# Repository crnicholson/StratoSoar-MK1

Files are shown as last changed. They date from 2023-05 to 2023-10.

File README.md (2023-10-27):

<picture>
 <source media="(prefers-color-scheme: dark)" srcset="https://github.com/charlienicholson3/StratoSoar/blob/main/schematic.png?raw=true">
 <source media="(prefers-color-scheme: light)" srcset="https://github.com/charlienicholson3/StratoSoar/blob/main/schematic.png?raw=true">
 YOUR-ALT-TEXT
</picture>

# UPDATE: This project is on its second year in a different repo as StratoSoar MK2. Link here: https://github.com/charlienicholsonr/StratoSoar-MK2.

### NOTE: This PCB is wrong. We had to add a wire to the board. I suggest designing your own PCB.

# StratoSoar MK1
My repo for the StratoSoar project. The LightAPRS code is just a variation of the original code. This system is made to recover unmanned high-altitude gliders, launched from weather balloons. It also has sensors that write to EEPROM, and the power for that system is controlled by the main MCU, which is the LightAPRS. For those who do not know, APRS is a form of HAM radio. You need to be a HAM radio operator to do it. For those who do not know, LightAPRS W-2 is a lightweight APRS transmitter: github.com/lightaprs/LightAPRS-W-2.0. The PCB takes anything from 20 to 6 volts as input and turns off the sensor and the camera after a certain altitude. It can also control the recording of the video. The schematic shows everything. The PCB breaks into three parts: top, middle, and bottom layers that connect through header pins.

# Acknowledgements
Thanks to Harish KC1SIO for the idea and initial work. Thanks to the NEWBS team for fostering the idea and having the high altitude project. Special thanks to Max W0MXX and Seth KC1PZY for funding and help during this project. Thanks to Bob K5TEC at NeSciTech for supplying a workspace and collaboration area. 

# Nerd info
We used a RunCam DVR with a 2N2222 transistor to close the circuit where the button is mounted. This took lots of development and didn't always go right. It highly depends on the voltage of the MCU and the amount of current your MCU can sink into the base pin of the transistor. Because of this, we had to not use the Serial Wombat and to solder a wire onto the LightAPRS. The SerialWombat can still be used to power the MOSFET, though it should be noted that the voltage goes through a series of transistor amplifiers to have enough voltage to turn on the FET. The camera on the DVR was a RunCam Atom.

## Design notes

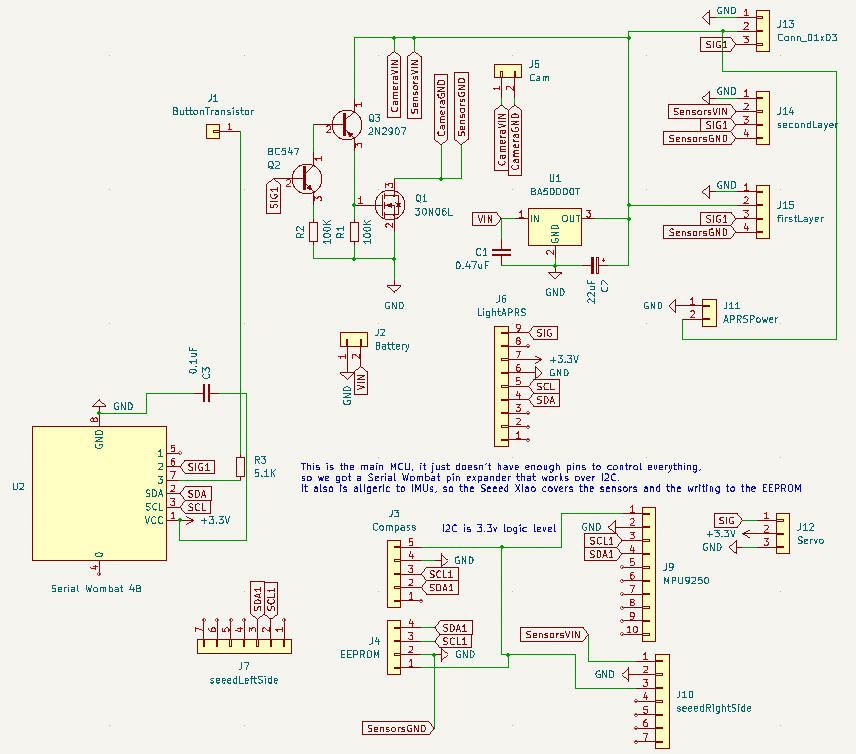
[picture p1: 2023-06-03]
schematic.png

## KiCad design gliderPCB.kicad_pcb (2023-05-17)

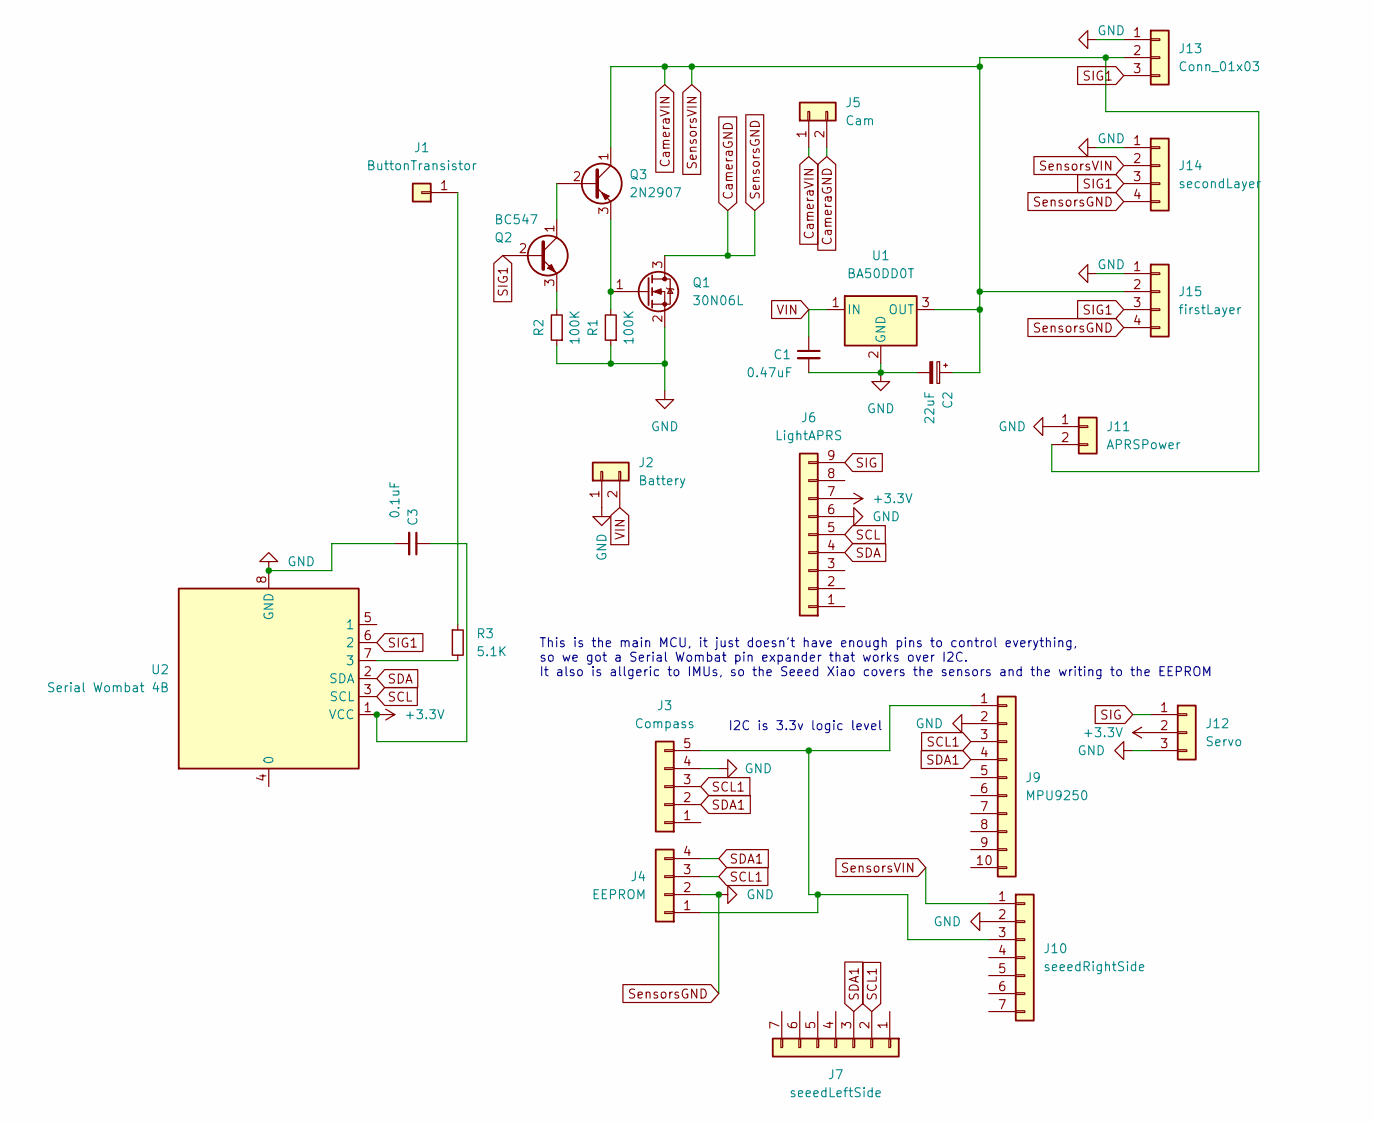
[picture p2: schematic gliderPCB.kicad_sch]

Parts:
C1: 0.47uF; C_Disc_D4.3mm_W1.9mm_P5.00mm
C2: 22uF; CP_Radial_D5.0mm_P2.50mm
C3: 0.1uF; C_Disc_D4.3mm_W1.9mm_P5.00mm
J1: ButtonTransistor; PinHeader_1x01_P2.54mm_Vertical
J2: Battery; PinHeader_1x02_P2.54mm_Vertical
J3: Compass; PinHeader_1x05_P2.54mm_Vertical
J4: EEPROM; PinHeader_1x04_P2.54mm_Vertical
J5: Cam; PinHeader_1x02_P2.54mm_Vertical
J6: LightAPRS; PinHeader_1x09_P2.54mm_Vertical
J7: seeedLeftSide; PinHeader_1x07_P2.54mm_Vertical
J9: MPU9250; PinHeader_1x10_P2.54mm_Vertical
J10: seeedRightSide; PinHeader_1x07_P2.54mm_Vertical
J11: APRSPower; PinHeader_1x02_P2.54mm_Vertical
J12: Servo; PinHeader_1x03_P2.54mm_Vertical
J13: Conn_01x03; PinHeader_1x03_P2.54mm_Vertical
J14: secondLayer; PinHeader_1x04_P2.54mm_Vertical
J15: firstLayer; PinHeader_1x04_P2.54mm_Vertical
Q1: 30N06L; TO-220-3_Vertical
Q2: BC547; TO-92L_Inline
Q3: 2N2907; TO-92L_Inline
R1, R2: 100K; R_Axial_DIN0207_L6.3mm_D2.5mm_P10.16mm_Horizontal
R3: 5.1K; R_Axial_DIN0207_L6.3mm_D2.5mm_P10.16mm_Horizontal
U1: BA50DD0T; TO-220F-3_Vertical
U2: Serial Wombat 4B; DIP-8_W7.62mm

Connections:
+3.3V: C3.1, J6.7, J12.2, U2.1 (VCC)
CameraGND: C1.2, C2.2, C3.2, J2.1, J3.4, J4.2, J5.2, J6.6, J9.2, J10.2, J11.1, J12.3, J13.1, J14.1, J14.4, J15.1, J15.4, Q1.2 (S), Q1.3 (D), R1.1, R2.1, U1.2 (GND), U2.8 (GND)
CameraVIN: C2.1, J5.1, J10.1, J11.2, J13.2, J14.2, J15.2, Q3.1 (C), U1.3 (OUT)
unnamed: J1.1, R3.1
unnamed: J3.5, J4.1, J9.1, J10.3
unnamed: Q1.1 (G), Q3.3 (E), R1.2
unnamed: Q2.1 (C), Q3.2 (B)
unnamed: Q2.3 (E), R2.2
unnamed: R3.2, U2.7 (3)
SCL: J6.5, U2.3 (SCL)
SCL1: J3.3, J4.3, J7.2, J9.3
SDA: J6.4, U2.2 (SDA)
SDA1: J3.2, J4.4, J7.3, J9.4
SIG: J6.9, J12.1
SIG1: J13.3, J14.3, J15.3, Q2.2 (B), U2.6 (2)
VIN: C1.1, J2.2, U1.1 (IN)

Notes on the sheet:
I2C is 3.3v logic level
This is the main MCU, it just doesn't have enough pins to control everything, so we got a Serial Wombat pin expander that works over I2C. It also is allgeric to IMUs, so the Seeed Xiao covers the sensors and the writing to the EEPROM

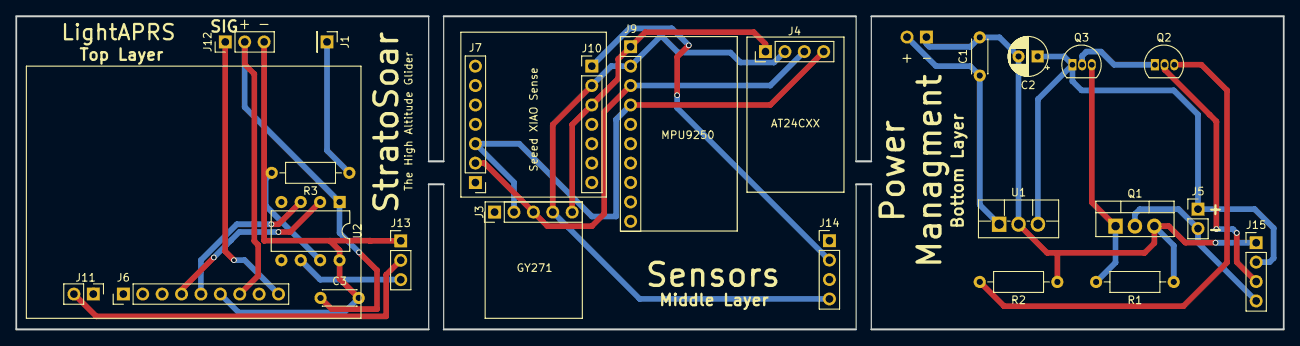
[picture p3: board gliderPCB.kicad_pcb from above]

Board: 2 copper layers, 166.0 x 41.0 mm, 25 parts (1 on the bottom side), 16 nets.

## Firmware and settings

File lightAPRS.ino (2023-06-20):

#include <Arduino.h>
#include <SPI.h>
#include <Wire.h>
#include <math.h>
#include <stdio.h>
#include <avr/dtostrf.h>
#include <ZeroAPRS.h>                       //https://github.com/hakkican/ZeroAPRS
#include <ZeroSi4463.h>                     //https://github.com/hakkican/ZeroSi4463
#include <TinyGPS++.h>                      //https://github.com/mikalhart/TinyGPSPlus
#include <GEOFENCE.h>                       // Modified version of https://github.com/TomasTT7/TT7F-Float-Tracker/blob/master/Software/ARM_GEOFENCE.c
#include <Adafruit_SleepyDog.h>             //https://github.com/adafruit/Adafruit_SleepyDog
#include <Adafruit_BMP085.h>                //https://github.com/adafruit/Adafruit-BMP085-Library
#include <si5351.h>                         //https://github.com/etherkit/Si5351Arduino
#include <JTEncode.h>                       //https://github.com/etherkit/JTEncode (JT65/JT9/JT4/FT8/WSPR/FSQ Encoder Library)
#include <TimeLib.h>                        //https://github.com/PaulStoffregen/Time
#include <Adafruit_ZeroTimer.h>             //https://github.com/adafruit/Adafruit_ZeroTimer
#include <MemoryFree.h>
#include <Servo.h>
#include <SerialWombat.h>

// line 580 is where the action begins
SerialWombat sw; // declare a Serial Wombat

#define Si5351Pwr     A3
#define TCXO_Pwr      A4
#define BattPin       A5
#define PTT_PIN       3
#define GpsPwr        7
#define Si446x_nIRQ   9
#define Si446x_SDN    4
#define Si446x_nSEL   8

//macros
#define Si5351ON    digitalWrite(Si5351Pwr, HIGH)//NPN
#define Si5351OFF   digitalWrite(Si5351Pwr, LOW)
#define GpsON       digitalWrite(GpsPwr, LOW)//PNP
#define GpsOFF      digitalWrite(GpsPwr, HIGH);
#define PttON       digitalWrite(PTT_PIN, HIGH)
#define PttOFF      digitalWrite(PTT_PIN, LOW)
#define Si4463ON    digitalWrite(Si446x_SDN, LOW)
#define Si4463OFF   digitalWrite(Si446x_SDN, HIGH)
#define TcxoON      digitalWrite(TCXO_Pwr, HIGH)
#define TcxoOFF     digitalWrite(TCXO_Pwr, LOW)

// #define DEVMODE // Development mode. Uncomment to enable for debugging.

//******************************  APRS CONFIG **********************************
char    CallSign[7]="KC1SFR";//DO NOT FORGET TO CHANGE YOUR CALLSIGN
int8_t  CallNumber=11; //11; //SSID http://www.aprs.org/aprs11/SSIDs.txt
char    Symbol='O'; // 'O' for balloon, '>' for car, for more info : http://www.aprs.org/symbols/symbols-new.txt
bool    alternateSymbolTable = false ; //false = '/' , true = '\'

char    comment[50] = "StratoSoar APRS Transmitter";// Max 50 char
char    StatusMessage[50] = "Made by KC1SFR and NEWBS";

uint32_t GEOFENCE_APRS_frequency      = 144390000 ;//default frequency before geofencing. This variable will be updated based on GPS location.
int32_t APRS_Freq_Correction          = -1200;     //Hz. vctcxo frequency correction for si4463

//*****************************************************************************

uint16_t  BeaconWait=50;  //seconds sleep for next beacon (HF or VHF). This is optimized value, do not change this if possible.
uint16_t  BattWait=60;    //seconds sleep if super capacitors/batteries are below BattMin (important if power source is solar panel) 
float     BattMin=3.3;    // min Volts to wake up.
float     GpsMinVolt=4.0; //min Volts for GPS to wake up. (important if power source is solar panel) 
float     WsprBattMin=4.0;//min Volts for HF (WSPR) radio module to transmit (TX) ~10 mW
float     HighVolt=10.0; //GPS is always on if the voltage exceeds this value to protect solar caps from overcharge

//******************************  HF (WSPR) CONFIG *************************************

char hf_call[7] = "NOCALL";// DO NOT FORGET TO CHANGE YOUR CALLSIGN

//#define WSPR_DEFAULT_FREQ       10140200UL //30m band
#define WSPR_DEFAULT_FREQ       14097100UL //20m band
//#define WSPR_DEFAULT_FREQ       18106100UL //17M band
//#define WSPR_DEFAULT_FREQ       21096100UL //15m band
//#define WSPR_DEFAULT_FREQ       24926100UL //12M band
//#define WSPR_DEFAULT_FREQ       28126100UL //10m band
//for all bands -> http://wsprnet.org/drupal/node/7352


// Supported modes, default HF mode is WSPR
enum mode {MODE_JT9, MODE_JT65, MODE_JT4, MODE_WSPR, MODE_FSQ_2, MODE_FSQ_3,
  MODE_FSQ_4_5, MODE_FSQ_6, MODE_FT8};
  
enum mode cur_mode = MODE_WSPR; //default HF mode

//supported other modes freq for 20m
#define JT9_DEFAULT_FREQ        14078700UL
#define FT8_DEFAULT_FREQ        14075000UL
#define JT65_DEFAULT_FREQ       14078300UL
#define JT4_DEFAULT_FREQ        14078500UL
#define FSQ_DEFAULT_FREQ        7105350UL     // Base freq is 1350 Hz higher than dial freq in USB

//*******************************************************************************


//******************************  APRS SETTINGS *********************************

//do not change WIDE path settings below if you don't know what you are doing :) 
uint8_t   Wide1=1; // 1 for WIDE1-1 path
uint8_t   Wide2=1; // 1 for WIDE2-1 path

/**
Airborne stations above a few thousand feet should ideally use NO path at all, or at the maximum just WIDE2-1 alone.  
Due to their extended transmit range due to elevation, multiple digipeater hops are not required by airborne stations.  
Multi-hop paths just add needless congestion on the shared APRS channel in areas hundreds of miles away from the aircraft's own location.  
NEVER use WIDE1-1 in an airborne path, since this can potentially trigger hundreds of home stations simultaneously over a radius of 150-200 miles. 
 */
uint8_t pathSize=2; // 2 for WIDE1-N,WIDE2-N ; 1 for WIDE2-N
boolean autoPathSizeHighAlt = true; //force path to WIDE2-N only for high altitude (airborne) beaconing (over 1.000 meters (3.280 feet)) 
boolean beaconViaARISS = true; //there are no iGates in some regions (such as North Africa,  Oceans, etc) so try to beacon via ARISS (International Space Station) https://www.amsat.org/amateur-radio-on-the-iss/

// Send aprs high precision position extension (adds 5 bytes to beacon messaage)
boolean send_aprs_enhanced_precision = true;
boolean  aliveStatus = true; //for tx status message on first wake-up just once.
boolean radioSetup = false; //do not change this, temp value
static char telemetry_buff[100];// telemetry buffer
uint16_t TxCount = 1; //increase +1 after every APRS transmission

//*******************************************************************************

//******************************  HF SETTINGS   *********************************

#define JT9_TONE_SPACING        174          // ~1.74 Hz
#define JT65_TONE_SPACING       269          // ~2.69 Hz
#define JT4_TONE_SPACING        437          // ~4.37 Hz
#define WSPR_TONE_SPACING       146          // ~1.46 Hz
#define FSQ_TONE_SPACING        879          // ~8.79 Hz
#define FT8_TONE_SPACING        625          // ~6.25 Hz

#define JT9_DELAY               576          // Delay value for JT9-1
#define JT65_DELAY              371          // Delay in ms for JT65A
#define JT4_DELAY               229          // Delay value for JT4A
#define WSPR_DELAY              683          // Delay value for WSPR
#define FSQ_2_DELAY             500          // Delay value for 2 baud FSQ
#define FSQ_3_DELAY             333          // Delay value for 3 baud FSQ
#define FSQ_4_5_DELAY           222          // Delay value for 4.5 baud FSQ
#define FSQ_6_DELAY             167          // Delay value for 6 baud FSQ
#define FT8_DELAY               159          // Delay value for FT8

#define HF_CORRECTION              -13000       // Change this for your ref osc
  
// Global variables
unsigned long hf_freq;
char hf_message[13] = "NOCALL AA00";//for non WSPR modes, you don't have to change this, updated by hf_call and GPS location
char hf_loc[] = "AA00";             //for WSPR, updated by GPS location. You don't have to change this.
uint8_t dbm = 10;
uint8_t tx_buffer[255];
uint8_t symbol_count;
uint16_t tone_delay, tone_spacing;
volatile bool proceed = false;


//*******************************************************************************


//******************************  GPS SETTINGS   *********************************
int16_t   GpsResetTime=1800; // timeout for reset if GPS is not fixed

// GEOFENCE 
uint32_t GEOFENCE_no_tx               = 0; //do not change this, temp value. 
boolean arissModEnabled = false; //do not change this, temp value. 

boolean GpsFirstFix=false; //do not change this
boolean ublox_high_alt_mode_enabled = false; //do not change this
int16_t GpsInvalidTime=0; //do not change this

//********************************************************************************

Si5351 si5351(0x60);
TinyGPSPlus gps;
Adafruit_BMP085 bmp;
JTEncode jtencode;
Si4463 si4463(Si446x_nIRQ, Si446x_SDN, Si446x_nSEL);
Adafruit_ZeroTimer zerotimer = Adafruit_ZeroTimer(3);

Servo servo;
int counter = 5;
bool validAlt = false;
bool validAlt2 = false;
bool isRecording = false;
int maxAddress = 5;
int addr = 0;
int prevAlt = 0;
int alt = 0;
int changedAlt = 0;

void setup() {
  Watchdog.enable(30000);
  Watchdog.reset();

  Wire.begin();
  bmp.begin();
  sw.begin(Wire, 0x6F);  // Initialize the Serial Wombat library to use the primary I2C port, this SerialWombat's address is 6F
  pinMode(A2, OUTPUT);
  digitalWrite(A2, LOW);
  sw.pinMode(2, OUTPUT);
  sw.digitalWrite(2, HIGH); // Turn on and off a few times to show initialization
  delay(1000);
  sw.digitalWrite(2, LOW);
  delay(1000);
  sw.digitalWrite(2, HIGH);
  
  // While the energy rises slowly with the solar panel, 
  // using the analog reference low solves the analog measurement errors.
  analogReference(AR_INTERNAL1V65);
  pinMode(PTT_PIN, OUTPUT);
  pinMode(Si5351Pwr, OUTPUT);
  pinMode(TCXO_Pwr, OUTPUT);
  pinMode(GpsPwr, OUTPUT);
  pinMode(BattPin, INPUT);
  pinMode(Si446x_SDN, OUTPUT);
  
  GpsOFF;
  Si5351OFF;  
  PttOFF;
  Si4463OFF;
  TcxoOFF;

  Serial.begin(9600);//GPS
  SerialUSB.begin(115200);
  // Wait up to 5 seconds for serial to be opened, to allow catching
  // startup messages on native USB boards (that do not reset when
  // serial is opened).
  Watchdog.reset();  
  unsigned long start = millis();
  while (millis() - start < 5000 && !SerialUSB){;}
  Watchdog.reset(); 

  SerialUSB.println(F("Starting"));

  APRS_init();
  APRS_setCallsign(CallSign, CallNumber);
  APRS_setDestination("APLIGA", 0);
  APRS_setPath1("WIDE1", Wide1);
  APRS_setPath2("WIDE2", Wide2);
  APRS_setPathSize(2);
  APRS_useAlternateSymbolTable(alternateSymbolTable);
  APRS_setSymbol(Symbol);
  APRS_setPathSize(pathSize);

  SerialUSB.println(F(""));
  SerialUSB.print(F("APRS (VHF) CallSign: "));
  SerialUSB.print(CallSign);
  SerialUSB.print(F("-"));
  SerialUSB.println(CallNumber);

  SerialUSB.print(F("WSPR (HF) CallSign: "));
  SerialUSB.println(hf_call);
  SerialUSB.println(F(""));
  
  servo.attach(A1);
  delay(1000);
  servo.write(0);
  delay(1000); 
  servo.write(90);
  delay(1000);
  servo.write(0);
  /*
  delay(10000);
  digitalWrite(A2, HIGH); // Start recording for 6.5 seconds to test the system
  delay(350);
  digitalWrite(A2, LOW);
  delay(6500);
  digitalWrite(A2, HIGH);
  delay(350);
  digitalWrite(A2, LOW);

  SerialUSB.println("Everything has initialized");
  */

  sw.digitalWrite(2, LOW);

  delay(500);
}

void loop() {
  Watchdog.reset();


if (((readBatt() > BattMin) && GpsFirstFix) || ((readBatt() > GpsMinVolt) && !GpsFirstFix)) {

    if (aliveStatus) {

      sendStatus();	  
      aliveStatus = false;

      while (readBatt() < BattMin) {
        sleepSeconds(BattWait); 
      }   
    }
    
      updateGpsData(1000);
      gpsDebug();

      if(gps.location.isValid() && gps.location.age()<1000){
        GpsInvalidTime=0;
      }else{
        GpsInvalidTime++;
        if(GpsInvalidTime > GpsResetTime){
          GpsOFF; 
          ublox_high_alt_mode_enabled = false; //gps sleep mode resets high altitude mode.
          Watchdog.reset();
          delay(1000);
          GpsON;
          GpsInvalidTime=0;     
        }
      }

      if ((gps.location.age() < 1000 || gps.location.isUpdated()) && gps.location.isValid()) {
        if (gps.satellites.isValid() && gps.satellites.value() > 3) {
          GpsFirstFix = true;
          if(readBatt() < HighVolt){
             GpsOFF; 
             ublox_high_alt_mode_enabled = false; //gps sleep mode resets high altitude mode.
          }      
          GpsInvalidTime=0;

          // Checks if there is an HF (WSPR) TX window is soon, if not then send APRS beacon
          if (!((minute() % 10 == 3 || minute() % 10 == 7) &&  second()>50 && readBatt() > WsprBattMin && timeStatus() == timeSet)){
             updateTelemetry();
            //APRS frequency isn't the same for the whole world. (for pico balloon only)
            if (!radioSetup || TxCount == 200) {
              configureFreqbyLocation();
            }

            if(!arissModEnabled && autoPathSizeHighAlt && gps.altitude.feet()>3000){
              //force to use high altitude settings (WIDE2-n)
              APRS_setPathSize(1);
            } else {
              //use default settings  
              APRS_setPathSize(pathSize);
            }

            //in some countries Airborne APRS is not allowed. (for pico balloon only)
            if (isAirborneAPRSAllowed()) {
              sendLocation();             

            }
            freeMem();
            SerialUSB.flush();

          }   

          // preparations for HF starts one minute before TX time at minute 3, 7, 13, 17, 23, 27, 33, 37, 43, 47, 53 or 57. No APRS TX during this period...
          if (readBatt() > WsprBattMin && timeStatus() == timeSet && ((minute() % 10 == 3) || (minute() % 10 == 7)) ) { 
            GridLocator(hf_loc, gps.location.lat(), gps.location.lng());
            sprintf(hf_message,"%s %s",hf_call,hf_loc);
            
            #if defined(DEVMODE)
            SerialUSB.println(F("Digital HF Mode Prepearing"));
            SerialUSB.print(F("Grid Locator: "));
            SerialUSB.println(hf_loc);
            #endif
            
            //HF transmission starts at minute 4, 8, 14, 18, 24, 28, 34, 38, 44, 48, 54 or 58 
            while (((minute() % 10 != 4) || (minute() % 10 != 8)) && second() != 0) {
              Watchdog.reset();
              delay(1);
            }
            #if defined(DEVMODE)
            SerialUSB.println(F("Digital HF Mode Sending..."));
            #endif          
            encode();
            //HFSent=true;

            #if defined(DEVMODE)
            SerialUSB.println(F("Digital HF Mode Sent"));
            #endif             
  
          } else {
            sleepSeconds(BeaconWait);
          }   
        }else {
          #if defined(DEVMODE)
          SerialUSB.println(F("Not enough sattelites"));
          #endif
        }
      }

    
  } else {
    sleepSeconds(BattWait);
  }
}

void sleepSeconds(int sec) {
  PttOFF;
  Si4463OFF;
  Si5351OFF;
  TcxoOFF;
  SerialUSB.flush();
  for (int i = 0; i < sec; i++) {
    if (GpsFirstFix){//sleep gps after first fix
      if (readBatt() < HighVolt){
        GpsOFF;
        ublox_high_alt_mode_enabled = false;
      }
    }else{
      if (readBatt() < BattMin){
        GpsOFF;
        ublox_high_alt_mode_enabled = false;
      }
    } 
     
    
    Watchdog.reset();
    delay(1000);
    
  }
  Watchdog.reset();
}

boolean isAirborneAPRSAllowed() {

  float tempLat = gps.location.lat();
  float tempLong = gps.location.lng();

  GEOFENCE_position(tempLat, tempLong);

  boolean airborne = true;

  if (GEOFENCE_no_tx == 1) {
    airborne = false;
  }

  return airborne;
}

boolean inARISSGeoFence(float tempLat, float tempLong) {
  boolean ariss = false;
  //North Africa
  if(tempLat>0 && tempLat<32 && tempLong>0 && tempLong<32){ariss = true;}
  //North Pacific
  if(tempLat>28 && tempLat<50 && tempLong>-180 && tempLong<-130){ariss = true;}
  //North Atlantic
  if(tempLat>25 && tempLat<42 && tempLong>-60 && tempLong<-33){ariss = true;} 
 
  return ariss;
}

void configureFreqbyLocation() {

  float tempLat = gps.location.lat();
  float tempLong = gps.location.lng();


  if(beaconViaARISS && inARISSGeoFence(tempLat, tempLong)) {
    APRS_setPath1("ARISS", Wide1);
    APRS_setPath2("WIDE2", Wide2);
    APRS_setPathSize(2);
    GEOFENCE_APRS_frequency=145825000;
    arissModEnabled = true;
  } else {

    GEOFENCE_position(tempLat,tempLong);      
    arissModEnabled = false;
  }  
  radioSetup = true;
}


void updatePosition(int high_precision, char *dao) {
  // Convert and set latitude NMEA string Degree Minute Hundreths of minutes ddmm.hh[S,N].
  char latStr[10];
  RawDegrees rawDeg = gps.location.rawLat();
  uint32_t min_nnnnn;
  char lat_dao = 0;
  min_nnnnn = rawDeg.billionths * 0.006;
  if ( ((min_nnnnn / (high_precision ? 1 : 100)) % 10) >= 5 && min_nnnnn < (6000000 - ((high_precision ? 1 : 100)*5)) ) {
    // round up. Avoid overflow (59.999999 should never become 60.0 or more)
    min_nnnnn = min_nnnnn + (high_precision ? 1 : 100)*5;
  }
  sprintf(latStr, "%02u%02u.%02u%c", (unsigned int ) (rawDeg.deg % 100), (unsigned int ) ((min_nnnnn / 100000) % 100), (unsigned int ) ((min_nnnnn / 1000) % 100), rawDeg.negative ? 'S' : 'N');
  if (dao)
    dao[0] = (char) ((min_nnnnn % 1000) / 11) + 33;
  APRS_setLat(latStr);

  // Convert and set longitude NMEA string Degree Minute Hundreths of minutes ddmm.hh[E,W].
  char lonStr[10];
  rawDeg = gps.location.rawLng();
  min_nnnnn = rawDeg.billionths * 0.006;
  if ( ((min_nnnnn / (high_precision ? 1 : 100)) % 10) >= 5 && min_nnnnn < (6000000 - ((high_precision ? 1 : 100)*5)) ) {
    min_nnnnn = min_nnnnn + (high_precision ? 1 : 100)*5;
  }
  sprintf(lonStr, "%03u%02u.%02u%c", (unsigned int ) (rawDeg.deg % 1000), (unsigned int ) ((min_nnnnn / 100000) % 100), (unsigned int ) ((min_nnnnn / 1000) % 100), rawDeg.negative ? 'W' : 'E');
  if (dao) {
    dao[1] = (char) ((min_nnnnn % 1000) / 11) + 33;
    dao[2] = 0;
  }

  APRS_setLon(lonStr);
  APRS_setTimeStamp(gps.time.hour(), gps.time.minute(),gps.time.second());
}


void updateTelemetry() {
  sprintf(telemetry_buff, "%03d", gps.course.isValid() ? (int)gps.course.deg() : 0);
  telemetry_buff[3] = '/';
  sprintf(telemetry_buff + 4, "%03d", gps.speed.isValid() ? (int)gps.speed.knots() : 0);
  telemetry_buff[7] = '/';
  telemetry_buff[8] = 'A';
  telemetry_buff[9] = '=';
  //sprintf(telemetry_buff + 10, "%06lu", (long)gps.altitude.feet());

  //fixing negative altitude values causing display bug on aprs.fi
  float tempAltitude = gps.altitude.feet();

  if (tempAltitude>0){
    //for positive values
    sprintf(telemetry_buff + 10, "%06lu", (long)tempAltitude);
  } else{
    //for negative values
    sprintf(telemetry_buff + 10, "%06d", (long)tempAltitude);
    } 
  
  telemetry_buff[16] = ' ';
  sprintf(telemetry_buff + 17, "%03d", TxCount);
  telemetry_buff[20] = 'T';
  telemetry_buff[21] = 'x';
  telemetry_buff[22] = 'C';
  telemetry_buff[23] = ' '; float tempC = bmp.readTemperature();
  dtostrf(tempC, 6, 2, telemetry_buff + 24);
  telemetry_buff[30] = 'C';
  telemetry_buff[31] = ' '; float pressure = bmp.readPressure() / 100.0; //Pa to hPa
  dtostrf(pressure, 7, 2, telemetry_buff + 32);
  telemetry_buff[39] = 'h';
  telemetry_buff[40] = 'P';
  telemetry_buff[41] = 'a';
  telemetry_buff[42] = ' ';
  dtostrf(readBatt(), 5, 2, telemetry_buff + 43);
  telemetry_buff[48] = 'V';
  telemetry_buff[49] = ' ';
  sprintf(telemetry_buff + 50, "%02d", gps.satellites.isValid() ? (int)gps.satellites.value() : 0);
  telemetry_buff[52] = 'S';
  telemetry_buff[53] = ' ';

  sprintf(telemetry_buff + 54, "%s", comment);  

  int servoPos = servo.read();
  char servoBuffer[10];
  itoa(servoPos, servoBuffer, 10); // Convert int to char array
  sprintf(telemetry_buff + 50, "%sP", servoBuffer); 
  SerialUSB.println(servo.read()); 

  // APRS PRECISION AND DATUM OPTION http://www.aprs.org/aprs12/datum.txt ; this extension should be added at end of beacon message.
  // We only send this detailed info if it's likely we're interested in, i.e. searching for landing position
  if (send_aprs_enhanced_precision && gps.altitude.feet() < 10000L && strlen(telemetry_buff) < sizeof(telemetry_buff) - 1 - 5 - 1) /* room for " !wAB!\0" */ {
    char dao[3];
    updatePosition(1, dao);
    sprintf(telemetry_buff + strlen(telemetry_buff), " !w%s!", dao);
  } else {
    updatePosition(0, NULL);
  }

#if defined(DEVMODE)
  SerialUSB.println(telemetry_buff);
#endif

}

void sendLocation() {
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

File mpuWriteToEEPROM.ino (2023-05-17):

/***************************************************************************
* Example sketch for the MPU9250_WE library
*
* This sketch shows how to measure pitch and roll angles from the MPU9250. 
* I have also included the corrected angle method for comparison.  
* 
* For further information visit my blog:
*
* https://wolles-elektronikkiste.de/mpu9250-9-achsen-sensormodul-teil-1  (German)
* https://wolles-elektronikkiste.de/en/mpu9250-9-axis-sensor-module-part-1  (English)
* 
***************************************************************************/

#include <MPU9250_WE.h>
#include <Wire.h>
#include <HMC5883L.h>

HMC5883L compass;

#define MPU9250_ADDR 0x68
#define EEPROM1_I2C_address 0x50

int maxAddress = 20;
int addr = 0;

/* There are several ways to create your MPU9250 object:
 * MPU9250_WE myMPU9250 = MPU9250_WE()              -> uses Wire / I2C Address = 0x68
 * MPU9250_WE myMPU9250 = MPU9250_WE(MPU9250_ADDR)  -> uses Wire / MPU9250_ADDR
 * MPU9250_WE myMPU9250 = MPU9250_WE(&wire2)        -> uses the TwoWire object wire2 / MPU9250_ADDR
 * MPU9250_WE myMPU9250 = MPU9250_WE(&wire2, MPU9250_ADDR) -> all together
 * Successfully tested with two I2C busses on an ESP32
 */
MPU9250_WE myMPU9250 = MPU9250_WE(MPU9250_ADDR);

void setup() {
  Serial.begin(115200);
  Wire.begin();
  if(!myMPU9250.init()){
    Serial.println("MPU9250 does not respond");
  }
  else{
    Serial.println("MPU9250 is connected");
  }

  // Initialize Initialize HMC5883L
  Serial.println("Initialize HMC5883L");
  while (!compass.begin())
  {
    Serial.println("Could not find a valid HMC5883L sensor, check wiring!");
    delay(500);
  }
  /* The slope of the curve of acceleration vs measured values fits quite well to the theoretical 
   * values, e.g. 16384 units/g in the +/- 2g range. But the starting point, if you position the 
   * MPU9250 flat, is not necessarily 0g/0g/1g for x/y/z. The autoOffset function measures offset 
   * values. It assumes your MPU9250 is positioned flat with its x,y-plane. The more you deviate 
   * from this, the less accurate will be your results.
   * The function also measures the offset of the gyroscope data. The gyroscope offset does not   
   * depend on the positioning.
   * This function needs to be called at the beginning since it can overwrite your settings!
   */
  Serial.println("Position you MPU9250 flat and don't move it - calibrating...");
  delay(1000);
  myMPU9250.autoOffsets();
  Serial.println("Done!");
  
  /*  This is a more accurate method for calibration. You have to determine the minimum and maximum 
   *  raw acceleration values of the axes determined in the range +/- 2 g. 
   *  You call the function as follows: setAccOffsets(xMin,xMax,yMin,yMax,zMin,zMax);
   *  Use either autoOffset or setAccOffsets, not both.
   */
  //myMPU9250.setAccOffsets(-14240.0, 18220.0, -17280.0, 15590.0, -20930.0, 12080.0);
  
  /*  Sample rate divider divides the output rate of the gyroscope and accelerometer.
   *  Sample rate = Internal sample rate / (1 + divider) 
   *  It can only be applied if the corresponding DLPF is enabled and 0<DLPF<7!
   *  Divider is a number 0...255
   */
  myMPU9250.setSampleRateDivider(5);

  /*  MPU9250_ACC_RANGE_2G      2 g    (default)
   *  MPU9250_ACC_RANGE_4G      4 g
   *  MPU9250_ACC_RANGE_8G      8 g   
   *  MPU9250_ACC_RANGE_16G    16 g
   */
  myMPU9250.setAccRange(MPU9250_ACC_RANGE_2G);

  /*  Enable/disable the digital low pass filter for the accelerometer 
   *  If disabled the bandwidth is 1.13 kHz, delay is 0.75 ms, output rate is 4 kHz
   */
  myMPU9250.enableAccDLPF(true);


  /*  Digital low pass filter (DLPF) for the accelerometer, if enabled 
   *  MPU9250_DPLF_0, MPU9250_DPLF_2, ...... MPU9250_DPLF_7 
   *   DLPF     Bandwidth [Hz]      Delay [ms]    Output rate [kHz]
   *     0           460               1.94           1
   *     1           184               5.80           1
   *     2            92               7.80           1
   *     3            41              11.80           1
   *     4            20              19.80           1
   *     5            10              35.70           1
   *     6             5              66.96           1
   *     7           460               1.94           1
   */
  myMPU9250.setAccDLPF(MPU9250_DLPF_6);  

  // Set measurement range
  compass.setRange(HMC5883L_RANGE_1_3GA);

  // Set measurement mode
  compass.setMeasurementMode(HMC5883L_CONTINOUS);

  // Set data rate
  compass.setDataRate(HMC5883L_DATARATE_30HZ);

  // Set number of samples averaged
  compass.setSamples(HMC5883L_SAMPLES_8);

  // Set calibration offset. See HMC5883L_calibration.ino
  compass.setOffset(121, -409);
}

void loop() {
  xyzFloat angles = myMPU9250.getAngles();

/* Pitch and roll consider all axes for calculation. According to my experience
   it provides more reliable results at higher angles (>60°) */
  float pitchRaw = myMPU9250.getPitch();
  float rollRaw  = myMPU9250.getRoll();
  
  int pitch = int(abs(pitchRaw));
  int roll = int(abs(rollRaw));

  Vector norm = compass.readNormalize();

  // Calculate heading
  float heading = atan2(norm.YAxis, norm.XAxis);

  // Set declination angle on your location and fix heading
  // You can find your declination on: http://magnetic-declination.com/
  // (+) Positive or (-) for negative
  // For Bytom / Poland declination angle is 4'26E (positive)
  // Formula: (deg + (min / 60.0)) / (180 / M_PI);
  float declinationAngle = (4.0 + (26.0 / 60.0)) / (180 / M_PI);
  heading += declinationAngle;

  // Correct for heading < 0deg and heading > 360deg
  if (heading < 0)
  {
    heading += 2 * PI;
  }

  if (heading > 2 * PI)
  {
    heading -= 2 * PI;
  }

  // Convert to degrees
  float headingDegrees = heading * 180/M_PI; 

  int temp = myMPU9250.getTemperature();
  
  static bool runCode = true;
  static int counter = 0; // address 0 is pitch, 1 is roll, 2 is heading, and 3 is temp in C
  
  if (runCode) { 
    writeToEEPROM(EEPROM1_I2C_address, addr, pitch);
    delay(10);
    Serial.println(readFromEEPROM(EEPROM1_I2C_address, addr), DEC);
    delay(10);
    addr++;
    writeToEEPROM(EEPROM1_I2C_address, addr, roll);
    delay(10);
    Serial.println(readFromEEPROM(EEPROM1_I2C_address, addr), DEC);
    delay(10);
    addr++;
    writeToEEPROM(EEPROM1_I2C_address, addr, int(headingDegrees));
    delay(10);
    Serial.println(readFromEEPROM(EEPROM1_I2C_address, addr), DEC);
    delay(10);
    addr++;
    writeToEEPROM(EEPROM1_I2C_address, addr, temp); // temp in C
    delay(10);
    Serial.println(readFromEEPROM(EEPROM1_I2C_address, addr), DEC);
    delay(10);
    addr++;
    
  counter++;
  if (counter >= maxAddress) {
    runCode = false;
  }
 }
  
  delay(1000);
  
}

void writeToEEPROM(byte EEPROMAddress, byte dataAddress, byte dataValue)
{
  Wire.beginTransmission(EEPROMAddress);
  Wire.write(dataAddress);
  Wire.write(dataValue);
  Wire.endTransmission();
  delay(5);
}
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

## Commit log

2023-05-17 StratoSoar gerber files
2023-05-17 Code for sensors
    Upload this to the Seeed Studio XIAO BLE Sense
